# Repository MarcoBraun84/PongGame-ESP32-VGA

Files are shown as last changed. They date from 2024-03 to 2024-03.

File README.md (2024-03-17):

# PongGame-ESP32-VGA
Es soll eine PONG-Spielekonsole entwickelt werden die für zwei Spieler ausgelegt ist und auf dem ESP32 Mikrokontroller basiert. 
Ziel des Projektes ist, mithilfe von zwei Lagesensoren (MPU6050) das Spiel Pong auf einem über VGA angesteuerten Monitor gegeneinander spielen zu können.
Drei Funktionsknöpfe ermöglichen, das Spiel zu pausieren und die KI1 bzw. KI2 ein- oder auszuschalten. 
Über ein Piezo werden Spielgeräusche, wie Ballaufprallgeräusche und Punktemelodie, erzeugt.

## Hardware


Benötigt werden folgende Komponenten:
- [ESP32-Entwicklerboard](https://www.reichelt.de/nodemcu-esp32-wifi-und-bluetooth-modul-debo-jt-esp32-p219897.html?&trstct=pos_0&nbc=1)
- 2x [MPU6050-Lagesensor](https://www.reichelt.de/entwicklerboards-beschleunigung-gyroskop-3-achsen-mpu-6050-debo-hmc5883l-2-p282539.html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)
- [Jumper Kabel / Steckbrückenkabel](https://www.reichelt.de/entwicklerboards-steckbrueckenkabel-20cm-3x-20-kabel-debo-kabelset8-p280591.html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)
- [VGA-Kabel](https://www.reichelt.de/vga-monitor-kabel-15-pol-vga-stecker-1-m-st-mxtmmhq1m-p274592.html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)
- 3x [Knöpfe](https://www.kaufland.de/product/419690543/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)
- 3x [10k Widerstände](https://www.reichelt.de/widerstand-kohleschicht-10-kohm-0207-250-mw-5--1-4w-10k-p1338.html)
- [Piezo](https://www.reichelt.de/de/de/piezo-schallwandler-85-db-4-khz-summer-epm-121-p35927.html?&trstct=pos_0&nbc=1)

#### VGA-Kabel vorbereiten
Die Bildübertragung benötigt 6 Adern (R, G, B, V-Syc, H-Syc, GND) des VGA-Kabels, um ein Bild mit 3-Bit-Farbraum zu übertragen. Diese können durch Jumper-Kabel direkt vom VGA-Kabelstecker abgegriffen werden (siehe Bild).

Alternativ kann das VGA-Kabel direkt verlötet werden. Hierbei bietet es sich an, die einzelnen Adern mit einer Durchgangsprüfung zu bestimmen.

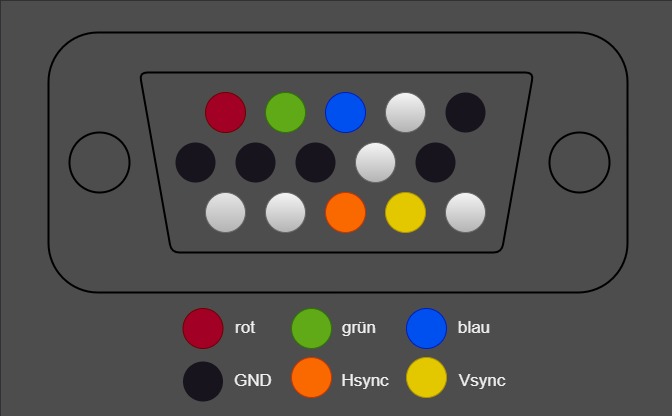
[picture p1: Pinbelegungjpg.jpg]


### Schaltplan:


Die Lagesensoren benötigen mindestens 3,3 V Versorgungsspannung und werden über einen I2C-Bus (SDA, SCL) verbunden. Der zweite Lagesensor erhält zusätzlich 3,3 V auf den I2C-Adresspin (AD0), damti dieser eine andere Busadresse erhält. Die Knöpfe schalten auf den HIGH-Zustand. Die Stromversorgung wird über den integrierten USB-C Eingang des ESP32 sichergestellt.

### 3D-Druck: Konsole, Kontroller
Ziel beim Entwickeln der Konsolen- und Kontroller-Gehäuse war es, ein möglichst modulares Konzept zu verfolgen, um alle Bauteile bei anderer Nutzung wieder verwenden zu können. Zudem sollte das Gehäuse keine Schrauben für die Montage benötigen.

Die [Modelle](https://github.com/tiimiiiiiiiiii/pong-esp32-vga/blob/main/3D-Druck%20Modelle.zip) benötigen folgende Druckeinstellungen:

```
Rafts:No
Supports:No
Infill:10%
Filament: PLA
Nozzel: 0.4 mm
Layer height: 0.2
Wall Line Count: 3
```

#### Konsolengehäuse
Gehäuse Konsole + Deckel

Im Konsolengehäuse sind Halterungen für den ESP32 und einen Piezo vorgesehen. 
Auf der Vorderseite befindet sich mittig ein "PONG" Schriftzug und zwei kleinere Spielerbezeichnungen, die für die passende Zuordnung der Kontroller und der darüber liegenden Funktionsknöpfe dienen.
An den beiden Seitenflächen befinden sich die Kabelausgänge der beiden Kontroller. 
Auf der rechten Seite befindet sich zudem eine größere Aussparung für den ESP32 USB-C Anschluss, der zugleich auch als Stromversogung dient.
Auf der Rückseite des Konsolengehäuses befindet sich der VGA-Kabelausgang.
Im Konsolendeckel wurden passende Aussparungen für die drei Knöpfe gelassen, die mit einem innenliegenden Steg verstärkt wurden. 

#### Kontrollergehäuse
Kontroller 1 2 Konstruktion + Real

Die Kontroller wurden so designt, dass der MPU6050 in das Gehäuse gesteckt werden kann und selbstständig hält. Auf der Oberseite befindet sich die Spielerbezeichnung P1 bzw. P2.
Die Kontroller-Form ermöglicht dem Spieler, den Kontroller einhändig auf dem Tisch oder zweihändig zu bedienen. 

## Software Installation
- [Arduino IDE](https://www.arduino.cc/en/software)
- [Library MPU6050](https://github.com/tiimiiiiiiiiii/pong-esp32-vga/blob/main/MPU6050_tockn.zip), [github Library MPU6050](https://github.com/Tockn/MPU6050_tockn)
- [Library MPU605069](https://github.com/tiimiiiiiiiiii/pong-esp32-vga/blob/main/MPU6050_tockn69.zip) (geänderte I2C-Adresse)
- [Library bitluni_ESP32Lib](https://github.com/tiimiiiiiiiiii/pong-esp32-vga/blob/main/bitluni_ESP32Lib.zip), [github bitluni ESP32lib](https://github.com/bitluni/ESP32Lib)

Um den Game-Code zu kompilieren und zu übertragen muss die Arduino IDE installiert werdem. Nach der Installation der IDE, müssen die Librarys installiert werden, um den Code ausführen zukönnen. Hierfür können in der IDE unter ```Sketch -> Include Library -> Add .ZIP Library``` die verlinkten Zip-Librarys installiert werden. Alternativ könnte man über ```Sketch -> Include Library -> Library Manger``` die Librarys suchen und installieren (nicht die modifizierte MPU605069-Library).

Weitherin muss das ESP32-Board hinzugefügt werden. Hierzu wird unter ```Tools -> Board -> Boards Manager...``` "esp32 by Espressif Systems" gesucht und installiert. Anschließend kann unter ```Tools -> Board -> esp32``` "ESP32 Dev Module" ausgewählt werden. Zum Hochladen des [PONG.ino](https://github.com/tiimiiiiiiiiii/pong-esp32-vga/blob/main/PONG.ino)-Codes muss nur noch unter ```Tools -> Port``` der angeschlossene ESP32-Port eingestellt werden.

### Spielvariablenliste
```bool Spielfeldbegrenzung = 1```: Bei Deaktivierung wird der Ball bei einem Treffer nicht "neu eingeworfen", sondern prallt vom linken bzw. rechten Bildschirmrand ab.

```bool Zufall_Ball = 0```: Bei Aktivierung wird der Ball beim Abprallen zufällig seine Geschwindigkeit ändern.

```bool Spielmodus1 = 1``` bzw. ```bool Spielmodus2 = 1```: Schaltet den KI-Spieler ein bzw. aus und wird von den jeweiligen Funktionsknöpfen beeinflusst. 

### VGA Monitor Ausgabe
Um eine Bildausgabe über den mit VGA angesteuerten Monitor zu erreichen, wurde die Library [bitluni ESP32lib](https://github.com/bitluni/ESP32Lib) verwendet. Mit unserem ESP32 ist eine maximale Auflösung von 320x240 Pixel möglich. 

Um beispielhaft einen Pong-Schriftzug über VGA auszugeben ist folgender Code nötig:  

```
#include <ESP32Lib.h>
#include <Ressources/CodePage437_8x19.h>

const int redPin = 14;
const int greenPin = 19;
const int bluePin = 27;
const int hsyncPin = 32;
const int vsyncPin = 33;

VGA3Bit vga;
vga.setFrameBufferCount(2);
Mode myMode = vga.MODE320x240;
myMode.print<HardwareSerial>(Serial);
vga.init(myMode, redPin, greenPin, bluePin, hsyncPin, vsyncPin);

void loop(){
  vga.clear(0);
  vga.setFont(CodePage437_8x19);
  vga.setCursor(vga.xres/2-35, vga.yres/2-10);
  vga.setTextColor(vga.RGB(255,0,0));
  vga.print("Pong Game!");
  vga.show();
}
```

### Pong Code
Als Grundlage diente [dieses Projekt](https://github.com/nickbild/pico_pong). Hieraus wurde der zugrundeliegende *Game Loop* und die *draw_player_paddle*-Funktion entnommen.
Daraus entstand die **Ball_Bewegung**-Funktion, die das Bewegungsverhalten, die Abprallgeräusche und die Darstellung des Balls übernimmt.
```
void Ball_Bewegung(){
  //Links
  if (B_Schlaeger + radius > ball_x) {
    vx = vx * - 1;
    Zufall();
    //Punkt P2
    if (ball_y > p1_y + H_Schlaeger || ball_y + radius < p1_y) point_scored(2);
    else tone(speaker_out, 440, 10);
  }
  //Rechts
  if (ball_x + radius > p2_x) {
    vx = vx * - 1;
    Zufall();
    //Punkt P1
    if (ball_y > p2_y + H_Schlaeger || ball_y + radius < p2_y) point_scored(1);
    else tone(speaker_out, 440, 10);
  }
  //Unten&Oben
  if (ball_y < 12 + radius || ball_y > 230 - radius) {
    vy = vy * -1;
    Zufall();
    tone(speaker_out, 500, 10);
  }
  ball_x = ball_x + vx;
  ball_y = ball_y + vy;
  vga.fillEllipse(ball_x, ball_y, radius, radius, vga.RGB(255, 255, 255));
}
```
- Zufall-Funktion: Verändert die Ballbewegung bei einem Abprall (```bool Zufall_Ball = 1```).
- tone-Funktion: Erzeugt über einen Piezo unterschiedliche Abprallgeräusche des Balls.
- vga.fillEllipse-Funktion: Erstellt das Bild des Balls.

Weiterhin entstand die **draw_player_paddle1**-Funktion, sowie die **draw_player_paddle2**-Funktion. Diese beinhalten die anschaltbaren KIs, die Spielereingabe und die Darstellung.

```
void draw_player_paddle1() {
  if (KI1_Zustand = 0) {
    Variation_1 = random(-2, 3)* H_Schlaeger;
    KI1_Zustand = 1;
  }
  //KI1
  if (Spielmodus1 == true && vx < 0) { 
    if (ball_y > p1_y + Variation_1) p1_y = p1_y + 1;
    else if (ball_y < p1_y + Variation_1) p1_y = p1_y - 1; 
  }
  //Oben & Unten-Problematik  
  if (p1_y < 11) p1_y = 11;
  if (p1_y > 190) p1_y = 190;
  vga.fillRect(p1_x, p1_y, B_Schlaeger, H_Schlaeger, vga.RGB(255, 255, 255));
}
```

### MPU6050 Steuerung
Leider unterstützt die genutzte Library [MPU6050_tockn](https://github.com/Tockn/MPU6050_tockn) keine Adressierung des MPU6050, wodurch mehrere MPUs nicht standardmäßig möglich sind. Lediglich durch Dublizieren dieser Library und Ändern der I2C-Adresse werden damit zwei MPUs ermöglicht (AD0 mit 3,3 V ändert die Adresse zu x069 mit [MPU605069-Library](https://github.com/tiimiiiiiiiiii/pong-esp32-vga/blob/main/MPU6050_tockn69.zip)).

Um die Funktion der beiden MPUs zu testen, kann der folgende Code verwendet werden. Hierbei werden über den seriellen Monitor die Werte der X-Achsen-Auslenkung ausgegeben.

```
#include <MPU6050_tockn.h>
#include <MPU6050_tockn69.h>

void setup(){
  MPU6050 mpu6050(Wire);
  MPU605069 mpu60502(Wire);
  Wire.begin();
  mpu6050.begin();
  mpu6050.calcGyroOffsets(true);
  mpu60502.begin();
  mpu60502.calcGyroOffsets(true);

void loop(){
  mpu6050.update();
  Serial.print("angleX : ");
  Serial.println(mpu6050.getAngleX());
  mpu60502.update();
  Serial.print("angleX2 : ");
  Serial.println(mpu60502.getAngleX());
}
```
Anmerkung: Beim Start des Codes wird eine automatische Kalibrierung der MPUs vorgenommen.

### Knopf-Funktion bzw. Debouncing
Für die drei Knöpfe wurde mit Hilfe [dieser Anleitung](https://docs.arduino.cc/built-in-examples/digital/Debounce) eine erweiterte Debounce-Funktion erstellt, die das Knopfsignal entprellt und damit einen klaren Knopfdruck sicher stellt.
```
const int buttonPin[] = {19, 13, 2};
int buttonState[] = {0, 0, 0}; 
int lastButtonState[] = {0, 0, 0};
unsigned long lastDebounceTime[] = {0, 0, 0};
unsigned long debounceDelay = 50;
---
int reading[] = {digitalRead(buttonPin[0]), digitalRead(buttonPin[1]), digitalRead(buttonPin[2])};
for (int i = 0; i < 3; i++) {
  if (reading[i] != lastButtonState[i]) lastDebounceTime[i] = millis();
  if ((millis() - lastDebounceTime[i]) > debounceDelay) {
    if (reading[i] != buttonState[i]) {
      buttonState[i] = reading[i];
      if (buttonState[0] == HIGH) Spielmodus1 = !Spielmodus1;
      if (buttonState[1] == HIGH) Spielmodus2 = !Spielmodus2;
      if (buttonState[2] == HIGH) Pause = !Pause;
    }
  }
  lastButtonState[i] = reading[i];
}
```

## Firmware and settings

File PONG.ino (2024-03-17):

#include <ESP32Lib.h>
#include <Ressources/Font6x8.h>
#include <Ressources/CodePage437_8x19.h>
#include <MPU6050_tockn.h>
#include <MPU6050_tockn69.h>

void Ball_Bewegung();
void point_scored(int player);
void draw_player_paddle1();
void draw_player_paddle2();
void Spielfeld();
void Zufall();
void Knoepfe();

//Pin Konfiguration VGA
const int redPin = 14;
const int greenPin = 25;
const int bluePin = 27;
const int hsyncPin = 32;
const int vsyncPin = 33;

//Pin Speaker
const int speaker_out = 23;

//Knöpfe
const int buttonPin[] = {19, 13, 4};
int buttonState[] = {0, 0, 0}; 
//Debounce
int lastButtonState[] = {0, 0, 0};
unsigned long lastDebounceTime[] = {0, 0, 0};
unsigned long debounceDelay = 50; 

//Konfiguration Spieler Schlaeger
const int B_Schlaeger = 5;
const int H_Schlaeger = 40;

const int p1_x = 0;
int p1_y = 100;
const int p2_x = 318 - B_Schlaeger; 
int p2_y = 100;

//Punktestand
int p1_score = 0;
int p2_score = 0;

// Ball Position und Physik
double vx = 1;
double vy = 1;
int ball_x = 50;
int ball_y = 150;

int radius = 3;

//Spielmodus
bool Pause = 0;
bool p = 1;
//true = KI, false = Spieler
bool Spielmodus1 = 1;
bool Spielmodus2 = 1;

//Spielfeldbegrenzung
bool Spielfeldbegrenzung = 1;

//KI Zustand
bool KI1_Zustand = 0;
double Variation_1 = 0;
bool KI2_Zustand = 0;
double Variation_2 = 0;

bool Zufall_Ball = 0;

VGA3Bit vga;

MPU6050 mpu6050(Wire);
MPU605069 mpu60502(Wire);

void setup(){
  Serial.begin(115200);
  vga.setFrameBufferCount(2);
	Mode myMode = vga.MODE320x240;
	//myMode.print<HardwareSerial>(Serial);
	vga.init(myMode, redPin, greenPin, bluePin, hsyncPin, vsyncPin);
  pinMode(speaker_out, OUTPUT);


//MPU6050
  Wire.begin();
  mpu60502.begin();
  mpu60502.calcGyroOffsets(true);
  mpu6050.begin();
  mpu6050.calcGyroOffsets(true);

//Knöpfe
  pinMode(buttonPin[0], INPUT);
  pinMode(buttonPin[1], INPUT);
  pinMode(buttonPin[2], INPUT);
}

void loop(){
  Knoepfe();
  if (Pause){
    if (p){
      vga.setFont(CodePage437_8x19);
	    vga.setCursor(vga.xres/2-20, vga.yres/3);
	    vga.setTextColor(vga.RGB(255,255,255));
	    vga.print("Pause");
      vga.show();
      p = 0;
    }
  } else {
    p = 1;
    vga.clear(0);
    Spielfeld();
    Ball_Bewegung();
    draw_player_paddle1();
    draw_player_paddle2();
    vga.show();
    delay(5);
  }
}

void Knoepfe(){
  int reading[] = {digitalRead(buttonPin[0]), digitalRead(buttonPin[1]), digitalRead(buttonPin[2])};
  for (int i = 0; i < 3; i++) {
    if (reading[i] != lastButtonState[i]) lastDebounceTime[i] = millis();
    if ((millis() - lastDebounceTime[i]) > debounceDelay) {
      if (reading[i] != buttonState[i]) {
        buttonState[i] = reading[i];
        if (buttonState[0] == HIGH) Spielmodus1 = !Spielmodus1;
        if (buttonState[1] == HIGH) Spielmodus2 = !Spielmodus2;
        if (buttonState[2] == HIGH) Pause = !Pause;
      }
    }
    lastButtonState[i] = reading[i];
  }
  if (mpu6050.getAngleX() > 4) p1_y--; 
  else if (mpu6050.getAngleX() < -5) p1_y++;
  mpu6050.update();
  
  if (mpu60502.getAngleX() > 3) p2_y--; 
  else if (mpu60502.getAngleX() < -7) p2_y++;
  mpu60502.update();

  Serial.print("X1: "); 
  Serial.print(mpu6050.getAngleX()); 
  Serial.print(";\t X2: "); 
  Serial.println(mpu60502.getAngleX()); 
}

void Ball_Bewegung(){
  //Links
  if (B_Schlaeger + radius > ball_x) {
    vx = vx * - 1;
    Zufall();
    //Punkt P2
    if (ball_y > p1_y + H_Schlaeger || ball_y + radius < p1_y) point_scored(2);
    else {
      tone(speaker_out, 440, 10);
      KI2_Zustand = 0;}
  }
  //Rechts
  if (ball_x + radius > p2_x) {
    vx = vx * - 1;
    Zufall();
    //Punkt P1
    if (ball_y > p2_y + H_Schlaeger || ball_y + radius < p2_y) point_scored(1);
    else {
      tone(speaker_out, 440, 10);
      KI1_Zustand = 0;}
  }
  //Unten&Oben
  if (ball_y < 12 + radius || ball_y > 230 - radius) {
    vy = vy * -1;
    Zufall();
    tone(speaker_out, 500, 10);
  }
  ball_x = ball_x + vx;
  ball_y = ball_y + vy;
  vga.fillEllipse(round(ball_x), round(ball_y), radius, radius, vga.RGB(255, 255, 255));
}

void Zufall(){
  if (Zufall_Ball) {
	  if (vx < 0) vx = -1 - 0.001*random(1, 1000);
	  else vx = 1 + 0.001*random(1, 1000);

	  if (vy < 0) vy = -1 - 0.001*random(2, 1000);
	  else vy = 1 + 0.001*random(2, 1000);
  }
}

void point_scored(int player) {
  KI1_Zustand = 0;
  KI2_Zustand = 0;
  //Punkte-Soundeffekt
  if (Spielfeldbegrenzung){
    tone(speaker_out, 500, 150);
    delay(300);
    tone(speaker_out, 500, 150);
    delay(100);
    tone(speaker_out, 500, 150);
    delay(100);
    tone(speaker_out, 600, 250);
    delay(500);
  }

  if (player == 1) {
    p1_score++;
    if (Spielfeldbegrenzung) {
      vx = 1;
      vy = 1;                                                 
      ball_x = B_Schlaeger + radius;
      ball_y = random(15, 225);
    }
  } 
  if (player == 2) {
    p2_score++;
    if (Spielfeldbegrenzung) {
      vx = -1;
      vy = 1;
      ball_x = p2_x - radius;
      ball_y = random(15, 225);
    }
  }
}

void draw_player_paddle1() {
  if (KI1_Zustand = 0) {
    Variation_1 = random(-3, 3)* H_Schlaeger;
    KI1_Zustand = 1;
  }
  //KI1
  if (Spielmodus1 == true && vx < 0) { 
    if (ball_y > p1_y + Variation_1) p1_y = p1_y + 1;
    else if (ball_y < p1_y + Variation_1) p1_y = p1_y - 1; 
  }
  //Oben & Unten-Problematik  
  if (p1_y < 11) p1_y = 11;
  if (p1_y > 190) p1_y = 190;
  vga.fillRect(p1_x, p1_y, B_Schlaeger, H_Schlaeger, vga.RGB(255, 255, 255));
}

void draw_player_paddle2() {
  if (KI2_Zustand = 0) {
    Variation_2 = random(-3, 3)* H_Schlaeger;
    KI2_Zustand = 1;
  }  
//KI2
  if (Spielmodus2 == true && vx > 0) { 
    if (ball_y > p2_y + Variation_2) p2_y = p2_y + 1;
    else if (ball_y < p2_y + Variation_2) p2_y = p2_y - 1; 
  } 

//Oben & Unten-Problematik 
  if (p2_y < 11) p2_y = 11; 
  if (p2_y > 190) p2_y = 190;
  vga.fillRect(p2_x, p2_y, B_Schlaeger, H_Schlaeger, vga.RGB(255, 255, 255));
}

void Spielfeld(){
  //Spielfeldbegrenzung oben&unten zeichnen
  vga.fillRect(0, 2, vga.xres, 10, vga.RGB(255, 255, 255));
  vga.fillRect(0, vga.yres - 8, vga.xres, 10, vga.RGB(255, 255, 255));

  //"PONG" Schriftzug
  vga.setFont(CodePage437_8x19);
	vga.setCursor(vga.xres/2-35, vga.yres/2-10);
	vga.setTextColor(vga.RGB(255,0,0));
	vga.print("Pong Game!");

  //Spieleranzeige Links
  vga.setFont(Font6x8);
  vga.setCursor(2, 4);
  if (Spielmodus1){
    vga.setTextColor(vga.RGB(0,0,255));
    vga.print("KI1:");
  } else {
    vga.setTextColor(vga.RGB(0));
    vga.print("P1:");
  }
  vga.print(p1_score);

  //Spileranzeige Rechts
  vga.setCursor(vga.xres-50, 4);
  if (Spielmodus2){
    vga.setTextColor(vga.RGB(0,0,255));
    vga.print("KI2:");
  } else {
    vga.setTextColor(vga.RGB(0));
    vga.print("P2:");
  }
	vga.print(p2_score);

  //Auflösung anzeigen
  vga.setTextColor(vga.RGB(0));
	vga.setCursor(2, vga.yres-8);
	vga.print(vga.xres);
	vga.print("x");
	vga.print(vga.yres);
}

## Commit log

2023-12-20 Add files via upload
    MPU6050 Library: Arduino IDE - Sketch - Include Library - ADD .ZIP-Library...
2023-12-20 MPU605069 Library für Arduino IDE ADD .ZIP
    MPU605069 Library: Arduino IDE -> Sketch -> Include Library -> ADD .ZIP-Library...
2023-12-20 MPU6050 Library für Arduino IDE ADD .ZIP
    MPU6050 Library: Arduino IDE -> Sketch -> Include Library -> ADD .ZIP-Library...
2023-12-20 ESP32Lib Library by bitluni
    ESP32Lib Library: Arduino IDE -> Sketch -> Include Library -> ADD .ZIP-Library...
    https://github.com/bitluni/ESP32Lib
2024-03-17 Add files via upload
    KiCad Schaltplan
    [PONG ESP32 Schaltplan.kicad_sch]
